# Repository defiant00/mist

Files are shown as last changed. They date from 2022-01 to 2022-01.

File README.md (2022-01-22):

# Mist

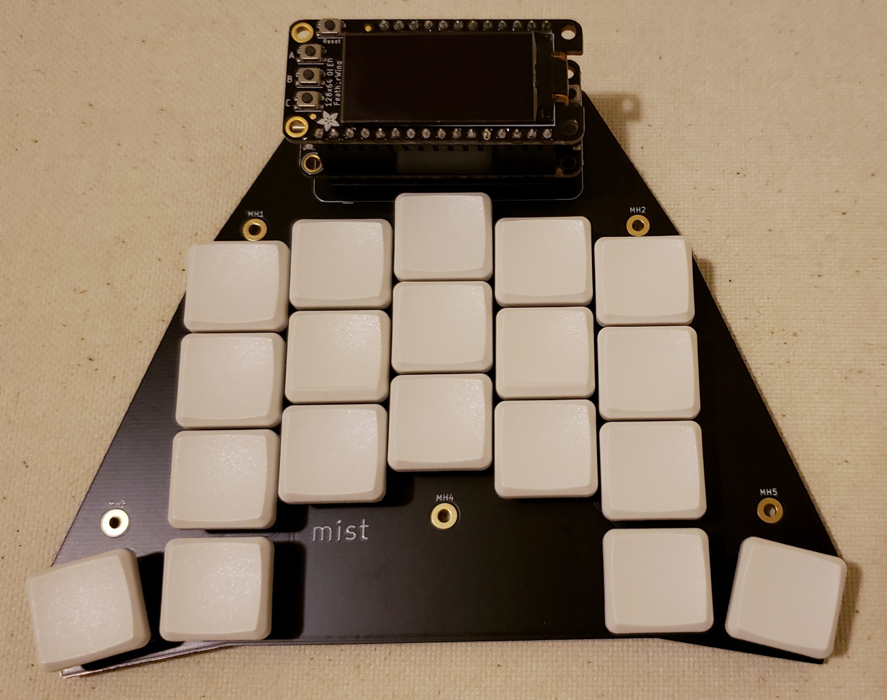
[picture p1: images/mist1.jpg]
mist


Mist is a one-handed symmetrical and columnar keyboard, with mirrored thumb keys providing 17 usable keys for either hand. It is ideal for anyone needing to type with one hand, or those wanting a staggered one-handed macro pad that can be used with either hand.

The name comes from its primary design goals: **MI**rrored, **ST**aggered.

Mist exists because accessibility should be more accessible. Commercial one-handed keyboards can be prohibitively expensive, and there are few open source keyboards designed specifically for one-handed use. Through this and the [purple firmware/layout project](https://github.com/defiant00/purple) we hope to provide another option.

## Parts

* 1x PCB
* 1x Adafruit Feather (recommended: [RP2040](https://www.adafruit.com/product/4884))
* 19x Kailh Choc switches
* 19x Choc spacing 1u keycaps (recommended: MBK)
* Some stick on feet
* **Optional**
  * Extra PCB as a bottom plate
  * M2 standoffs and screws
  * Adafruit Featherwings (OLEDs, LEDs, etc.) or STEMMA QT accessories if your Feather supports them

## Assembly

1. Solder on the Feather and switches. You can slot the Feather if you prefer.
2. **Optional** - Attach the extra PCB as a bottom plate using standoffs and screws at the five mounting points.
3. Keycaps!
4. Apply feet near the corners of the board.

## Release Notes

### 1.0 [2022-01-02]

* Initial version

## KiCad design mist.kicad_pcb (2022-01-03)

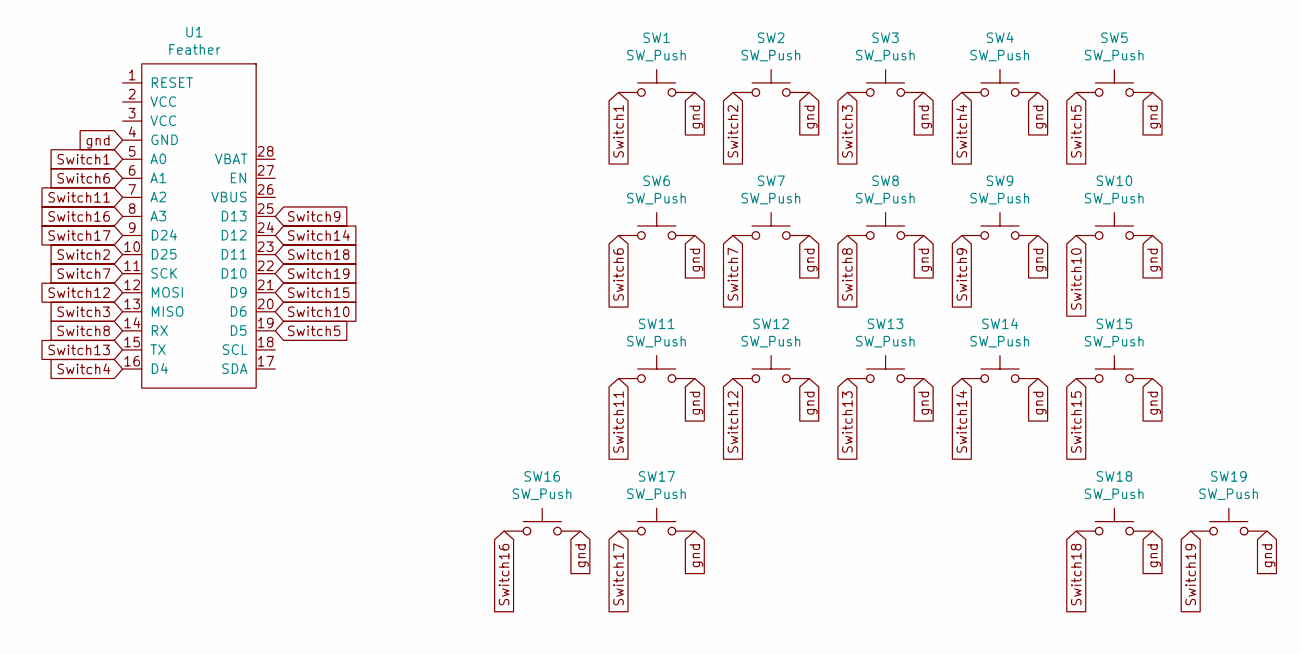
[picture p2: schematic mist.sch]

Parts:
SW1, SW2, SW3, SW4, SW5, SW6, SW7, SW8, SW9, SW10, SW11, SW12, SW13, SW14, SW15, SW16, SW17, SW18, SW19: SW_Push; Kailh-PG1350-1u-Clickhole-NoLED
U1: Feather; Adafruit_Feather

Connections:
Switch1: SW1.1, U1.5 (A0)
Switch2: SW2.1, U1.10 (D25)
Switch3: SW3.1, U1.13 (MISO)
Switch4: SW4.1, U1.16 (D4)
Switch5: SW5.1, U1.19 (D5)
Switch6: SW6.1, U1.6 (A1)
Switch7: SW7.1, U1.11 (SCK)
Switch8: SW8.1, U1.14 (RX)
Switch9: SW9.1, U1.25 (D13)
Switch10: SW10.1, U1.20 (D6)
Switch11: SW11.1, U1.7 (A2)
Switch12: SW12.1, U1.12 (MOSI)
Switch13: SW13.1, U1.15 (TX)
Switch14: SW14.1, U1.24 (D12)
Switch15: SW15.1, U1.21 (D9)
Switch16: SW16.1, U1.8 (A3)
Switch17: SW17.1, U1.9 (D24)
Switch18: SW18.1, U1.23 (D11)
Switch19: SW19.1, U1.22 (D10)
gnd: SW1.2, SW2.2, SW3.2, SW4.2, SW5.2, SW6.2, SW7.2, SW8.2, SW9.2, SW10.2, SW11.2, SW12.2, SW13.2, SW14.2, SW15.2, SW16.2, SW17.2, SW18.2, SW19.2, U1.4 (GND)

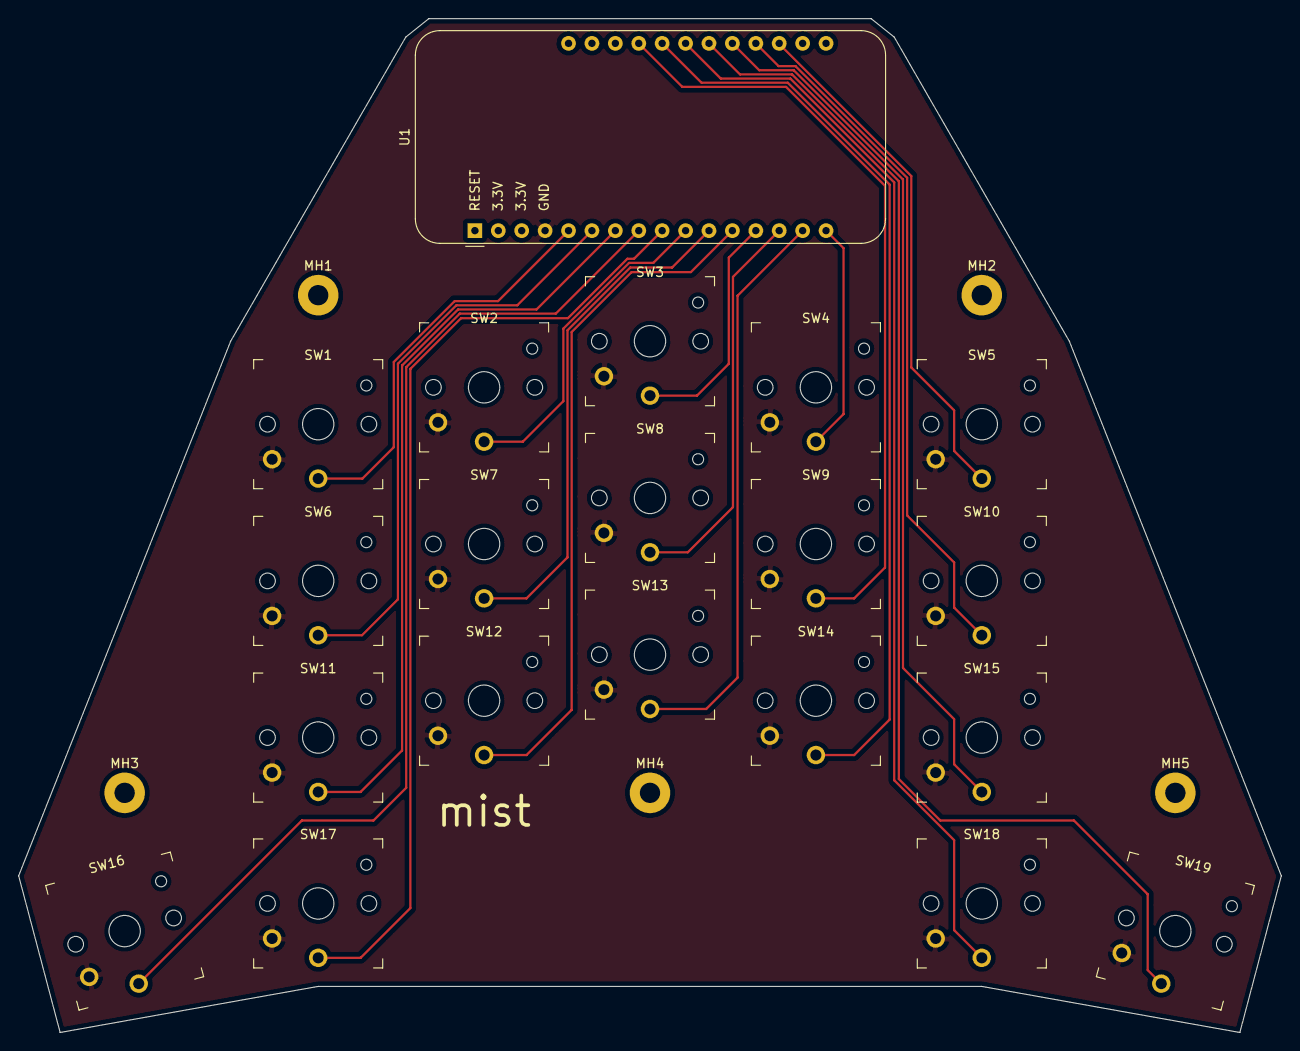
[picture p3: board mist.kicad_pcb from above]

Board: 2 copper layers, 137.0 x 110.0 mm, 25 parts (0 on the bottom side), 20 nets.

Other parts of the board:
MH1, MH2, MH3, MH4, MH5: MountingHole_2.2mm_M2_Pad

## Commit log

2022-01-02 initial version
    [mist.kicad_pcb, mist.sch]
2022-01-03 added clickhole and gerbers
    [mist.kicad_pcb, mist.sch]
2022-01-22 added parts and assembly
